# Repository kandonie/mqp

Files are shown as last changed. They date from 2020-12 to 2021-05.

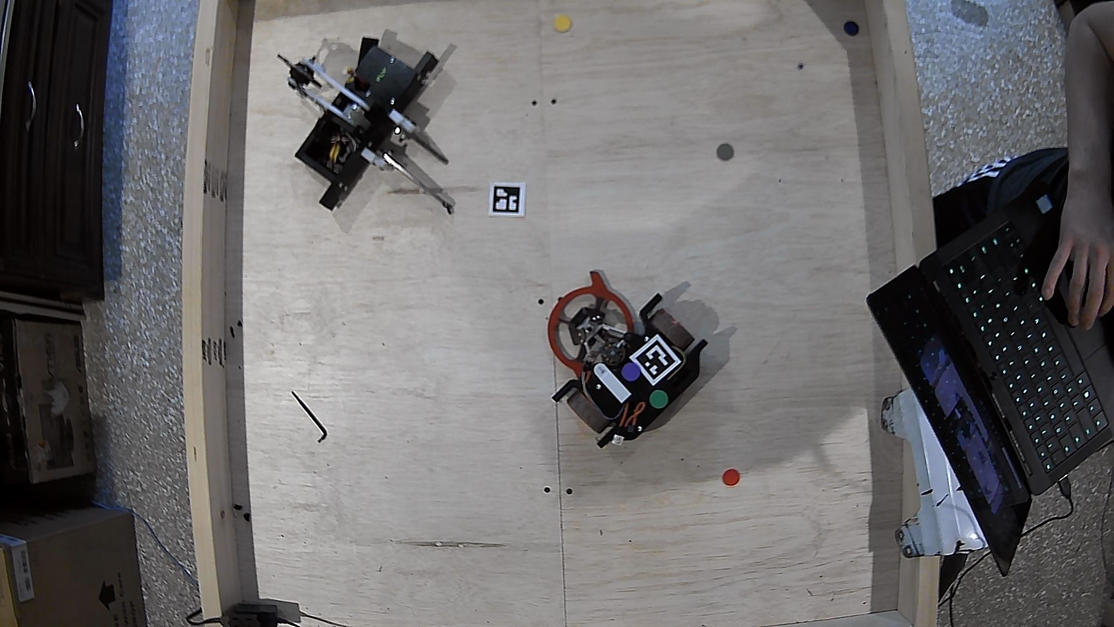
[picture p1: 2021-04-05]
src/CV/tags/OnFiled.png

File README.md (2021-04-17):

To run application:
    python3 main.py <shouldConnectToWiFi> <liveInference>

To run tests:
    python -m pytest tests

shouldConnectToWiFi defaults to True. True tries to connect to WiFi. False will never try to connect
but will also load faster. Good for testing without the ESP
liveInference default to True. true means detecting with webcam, false is using stored images

Currently, things happen based on the GUI. When there is
a change in the GUI, the GUI notifies the state machine (which 
observers the GUI). The state machine's notify currently calls 
appropriate functions on the drive and motor. These call functions
in WiFi to send json info the the ESP. The ESP then makes appropriate
corresponding actions. In the near future, the state machine's notify 
will only update variables. The the runStateMachine will call 
appropriate functions based on those variables.

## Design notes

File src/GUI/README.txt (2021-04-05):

The GUI allows the user to do several things, including viewing data and sending instructions.

The first important feature to note is the ESTOP button in the top left. This will stop the robot.
To the right of this button, we have enable/disable drive and weapon. These buttons determine if
the corresponding motors can more, regaurdless of any state of autonomy.

Next is the intelligence state. Idle means the robot will do nothing. Selecting Remote Control will
open a new window and allow you to drive the robot with the arrow keys. Further instructions reside in
this window. Closing the window brings you back to the main window. Autonomous means the robot will
exercise some autonomous control. For example, you can set the pwm with the GUI and it will move (assuming
drive is enabled), or it may enter a match. The begin match button tells the robot that it is beginning
a combat match and will begin executing the appropriate states of its state maching. Match over sends the
robot into the match over state, where it will perform appropriate actions for a match being over, such as
driving to the door or turning off. Finally, the reset match button reinitializes the robot.

Moving downward, on the left, one can see various data about the robot, provided by the robot. On the right,
the image used by the CV is shown. These are each updated every 500 ms.

At the bottom of the screen lies manual controls for testing the robot. The first column allows you to set
the pwm value of each motor when the button is clicked. The next column allows you to sed the PID values
for all motors when the button is clicked. The next button, set heading, allows you to choose which angle
the robot should turn to face when the button is clicked. Finally, the set distance button tells the robot
to drive a certain distance when clicked.

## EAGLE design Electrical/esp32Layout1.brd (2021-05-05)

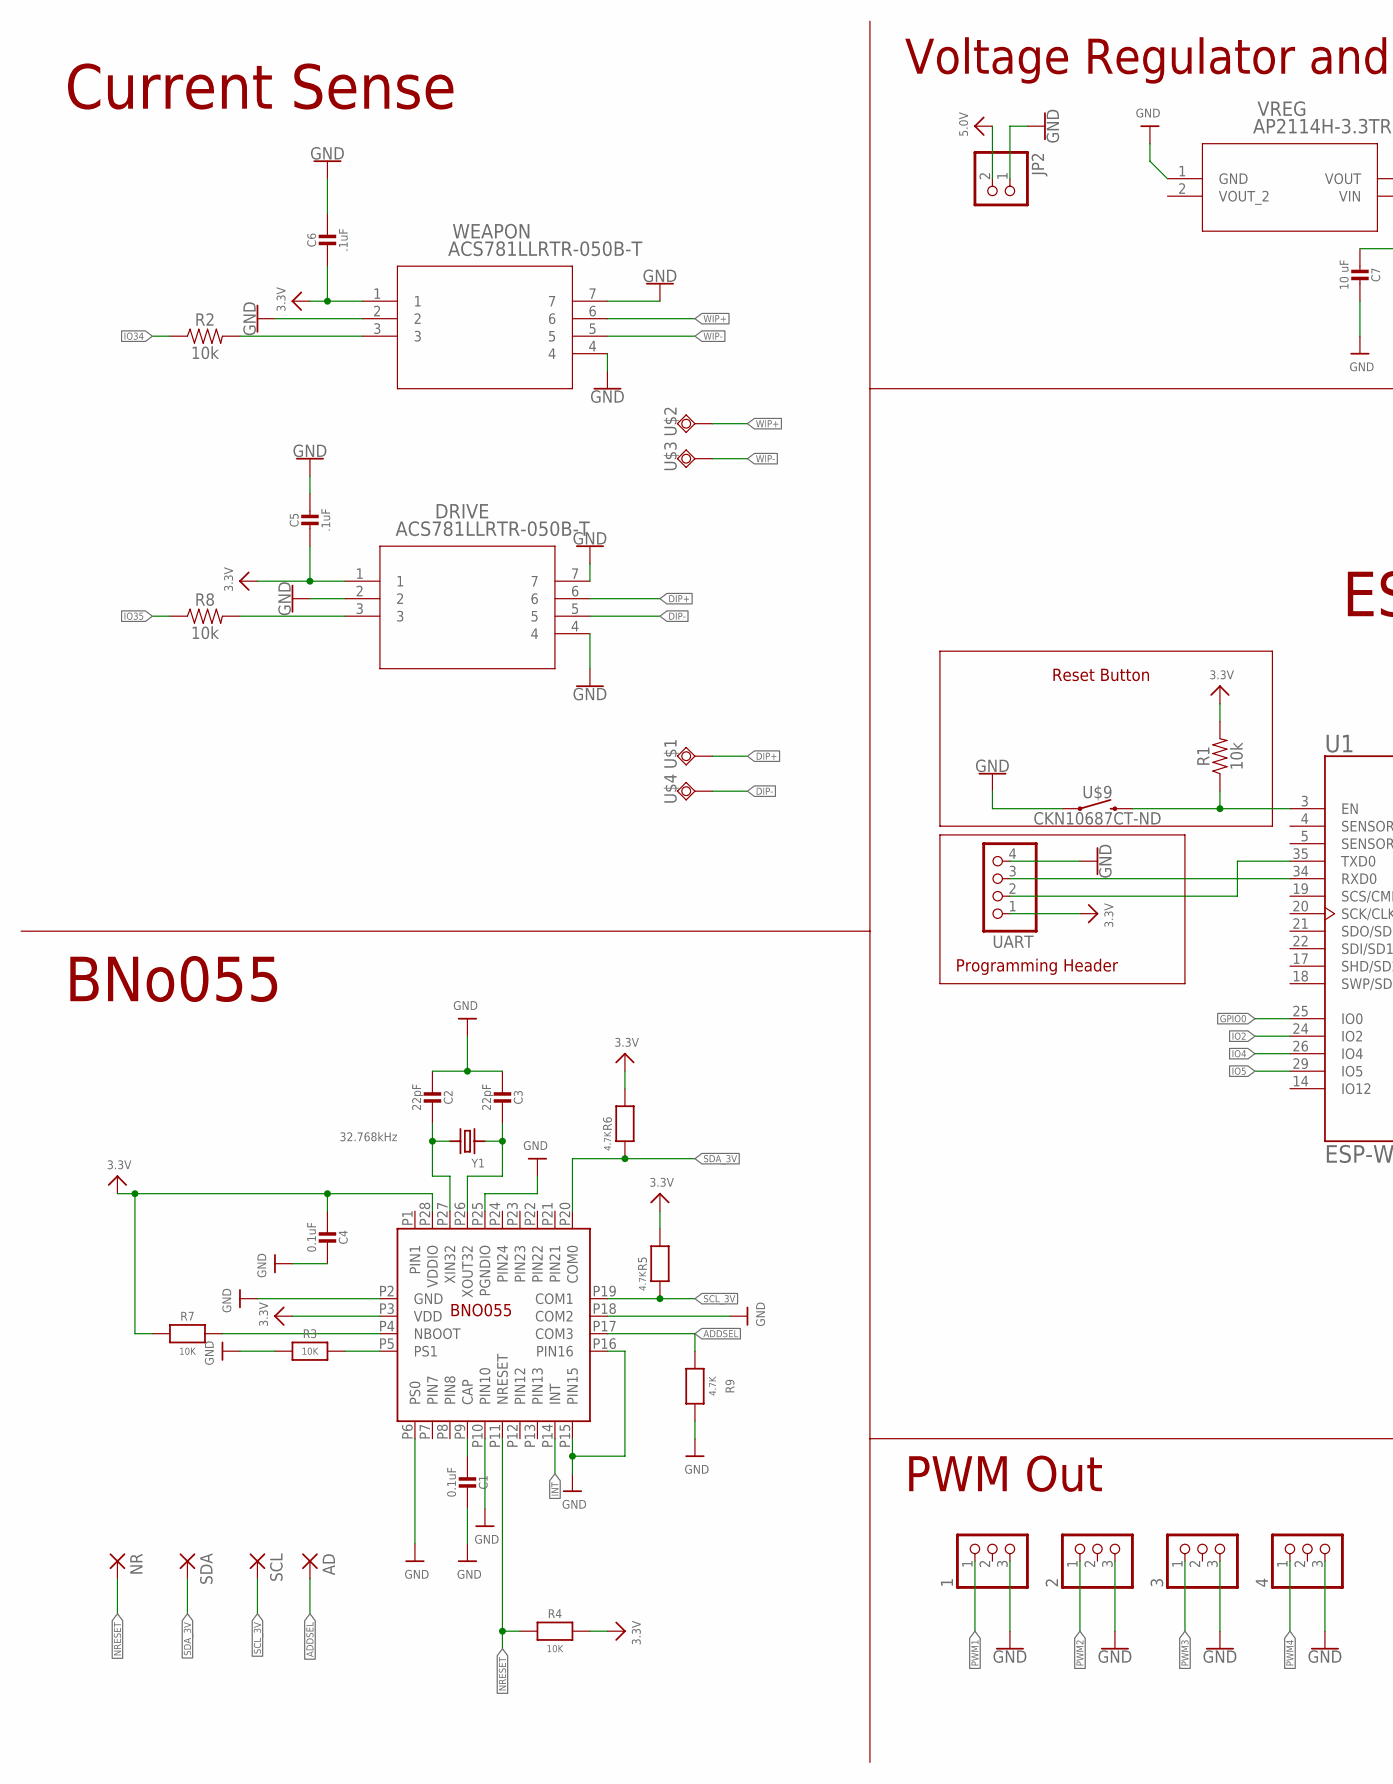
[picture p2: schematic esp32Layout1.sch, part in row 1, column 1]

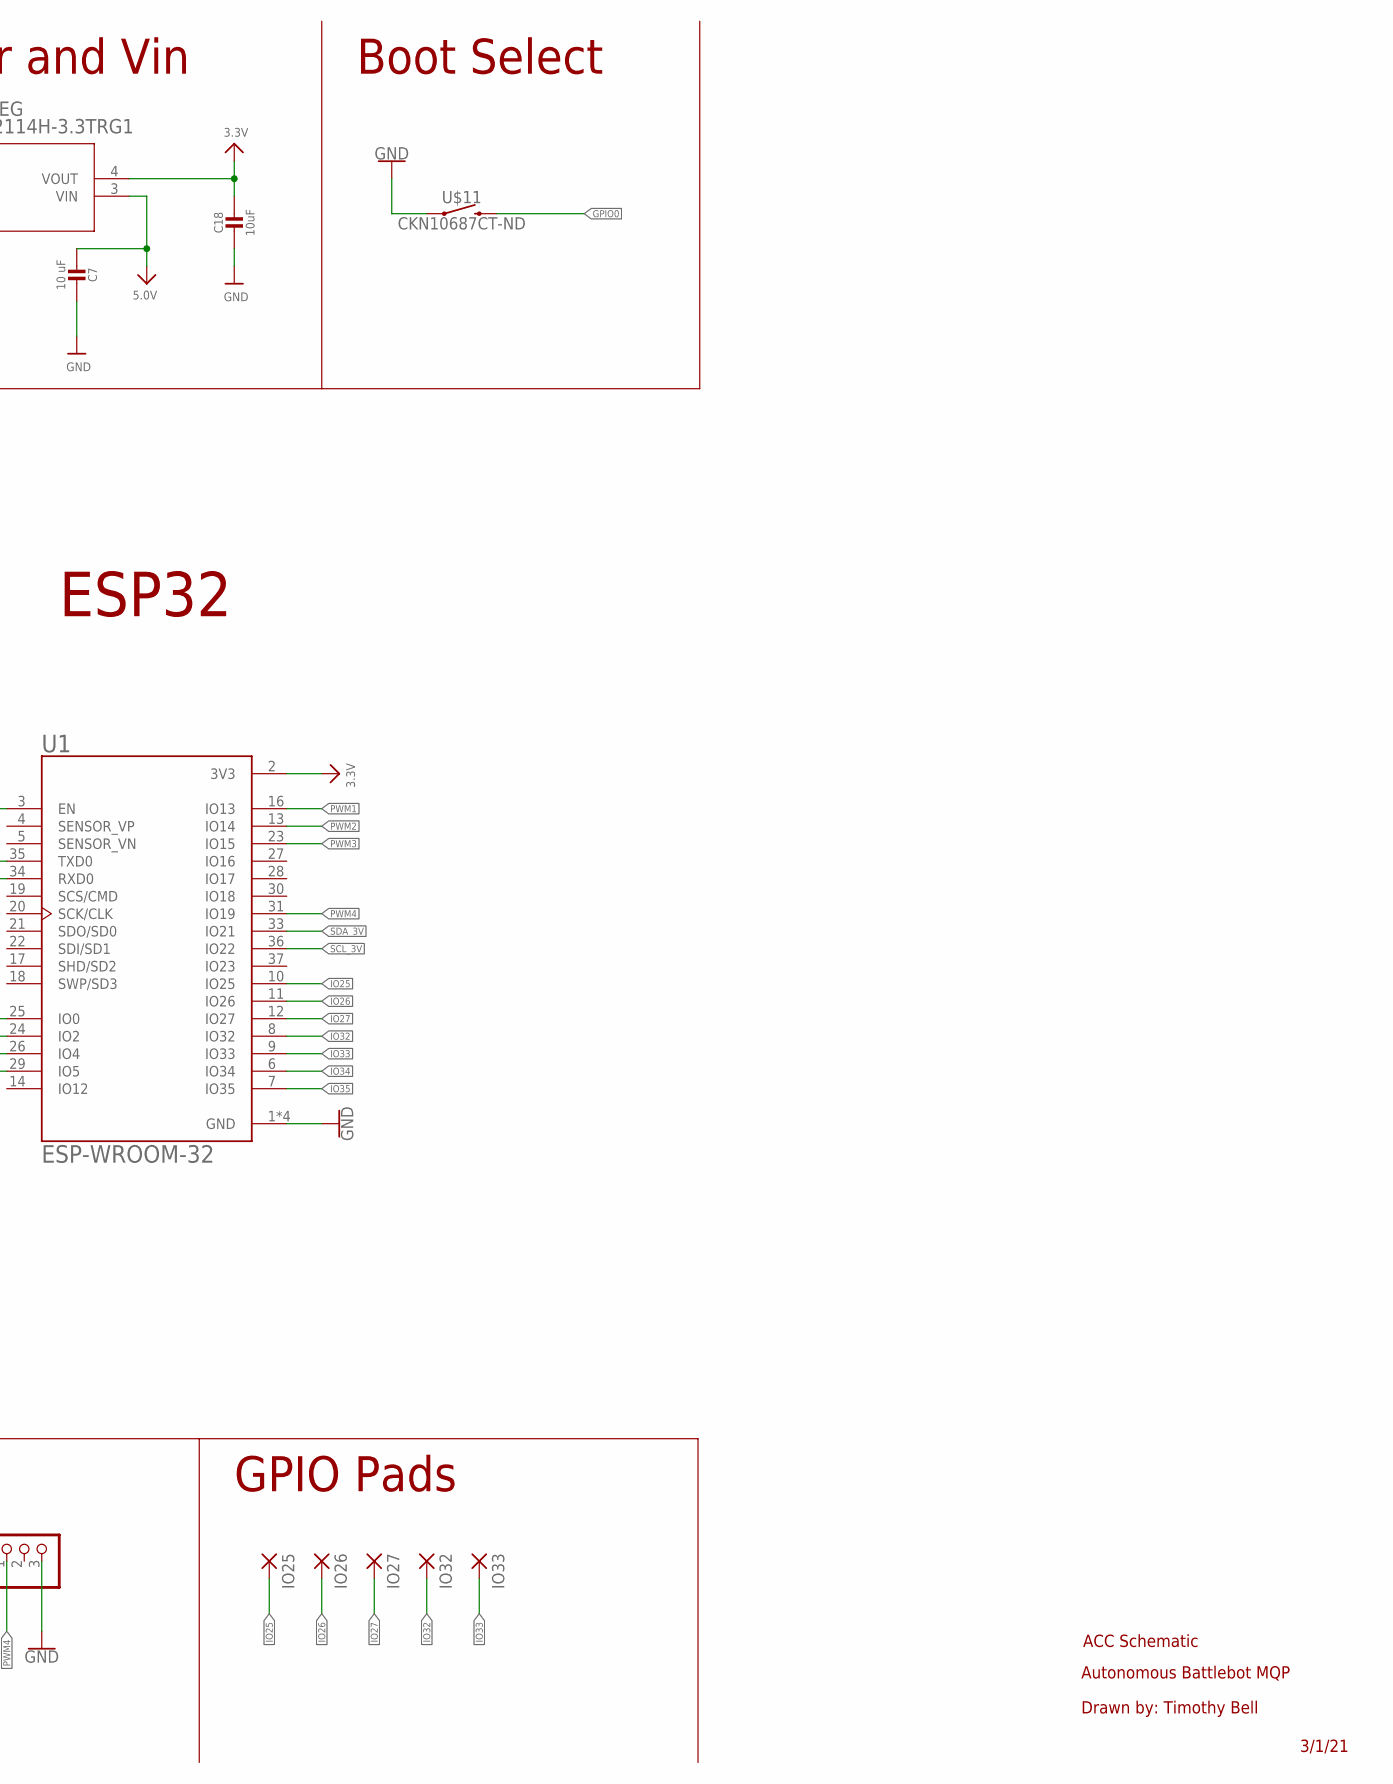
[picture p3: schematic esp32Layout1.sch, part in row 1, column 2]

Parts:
1, 2, 3, 4: PINHD-1X3; 1X03
AD: SMD2; SMD1,27-2,54
BNO055: BNO055
C1, C4: 0.1uF; 0805-NO
C2, C3: 22pF; 0805-NO
C5, C6: .1uF; 0805_10MGAP
C7: 10 uF; 0805-NO
C18: 10uF; 0805_10MGAP
DRIVE: ACS781LLRTR-050B-T; PSOF7_ACS781LLRTR-050B-T_ALM
IO25, IO26, IO27, IO32, IO33: SMD2; SMD1,27-2,54
JP2: PINHD-1X2; 1X02
NR: SMD2; SMD1,27-2,54
R1, R2, R8: 10k; 0603
R3, R4, R7: 10K; 0805-NO
R5, R6, R9: 4.7K; 0805-NO
SCL: SMD2; SMD1,27-2,54
SDA: SMD2; SMD1,27-2,54
U1: ESP-WROOM-32; MODULE_ESP-WROOM-32
U$1, U$2, U$3, U$4: HCURR_PAD
U$9, U$11: CKN10687CT-ND
UART: PINHD-1X4; 1X04
VREG: AP2114H-3.3TRG1; SOT-223_DIO
WEAPON: ACS781LLRTR-050B-T; PSOF7_ACS781LLRTR-050B-T_ALM
Y1: 32.768kHz; CRYSTAL_8X3.8

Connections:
3.3V: BNO055.P3 (VDD), BNO055.P28 (VDDIO), C4.2, C5.2, C6.2, C18.1, DRIVE.1, R1.2, R4.2, R5.2, R6.2, R7.1, U1.2 (3V3), UART.1, VREG.4 (VOUT), WEAPON.1
5.0V: C7.2, JP2.2, VREG.3 (VIN)
ADDSEL: AD.1, BNO055.P17 (COM3), R9.1
DIP+: DRIVE.6, U$1.P$1
DIP-: DRIVE.5, U$4.P$1
GND: 1.3, 2.3, 3.3, 4.3, BNO055.P2 (GND), BNO055.P6 (PS0), BNO055.P10 (PIN10), BNO055.P15 (PIN15), BNO055.P16 (PIN16), BNO055.P18 (COM2), BNO055.P25 (PGNDIO), C1.1, C2.2, C3.2, C4.1, C5.1, C6.1, C7.1, C18.2, DRIVE.2, DRIVE.4, DRIVE.7, JP2.1, R3.1, R9.2, U1.1 (GND), U1.1.1 (GND), U1.15 (GND), U1.38 (GND), U$9.P$1 (1), U$9.P$2 (1), U$11.P$1 (1), U$11.P$2 (1), UART.4, VREG.1 (GND), WEAPON.2, WEAPON.4, WEAPON.7
GPIO0: U1.25 (IO0), U$11.P$3 (2), U$11.P$4 (2)
INT: BNO055.P14 (INT)
IO2: U1.24 (IO2)
IO4: U1.26 (IO4)
IO5: U1.29 (IO5)
IO25: IO25.1, U1.10 (IO25)
IO26: IO26.1, U1.11 (IO26)
IO27: IO27.1, U1.12 (IO27)
IO32: IO32.1, U1.8 (IO32)
IO33: IO33.1, U1.9 (IO33)
IO34: R2.1, U1.6 (IO34)
IO35: R8.1, U1.7 (IO35)
unnamed: BNO055.P5 (PS1), R3.2
unnamed: R1.1, U1.3 (EN), U$9.P$3 (2), U$9.P$4 (2)
unnamed: U1.35 (TXD0), UART.2
unnamed: U1.34 (RXD0), UART.3
unnamed: R2.2, WEAPON.3
unnamed: BNO055.P9 (CAP), C1.2
unnamed: BNO055.P27 (XIN32), C2.1, Y1.P$4 (2)
unnamed: BNO055.P26 (XOUT32), C3.1, Y1.P$1 (1)
unnamed: BNO055.P4 (NBOOT), R7.2
unnamed: DRIVE.3, R8.2
NRESET: BNO055.P11 (NRESET), NR.1, R4.1
PWM1: 1.1, U1.16 (IO13)
PWM2: 2.1, U1.13 (IO14)
PWM3: 3.1, U1.23 (IO15)
PWM4: 4.1, U1.31 (IO19)
SCL_3V: BNO055.P19 (COM1), R5.1, SCL.1, U1.36 (IO22)
SDA_3V: BNO055.P20 (COM0), R6.1, SDA.1, U1.33 (IO21)
WIP+: U$2.P$1, WEAPON.6
WIP-: U$3.P$1, WEAPON.5

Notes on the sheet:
BNo055
ESP32
Current Sense
PWM Out
Voltage Regulator and Vin
GPIO Pads
Boot Select
ACC Schematic
Autonomous Battlebot MQP
Drawn by: Timothy Bell
3/1/21
Reset Button
Programming Header

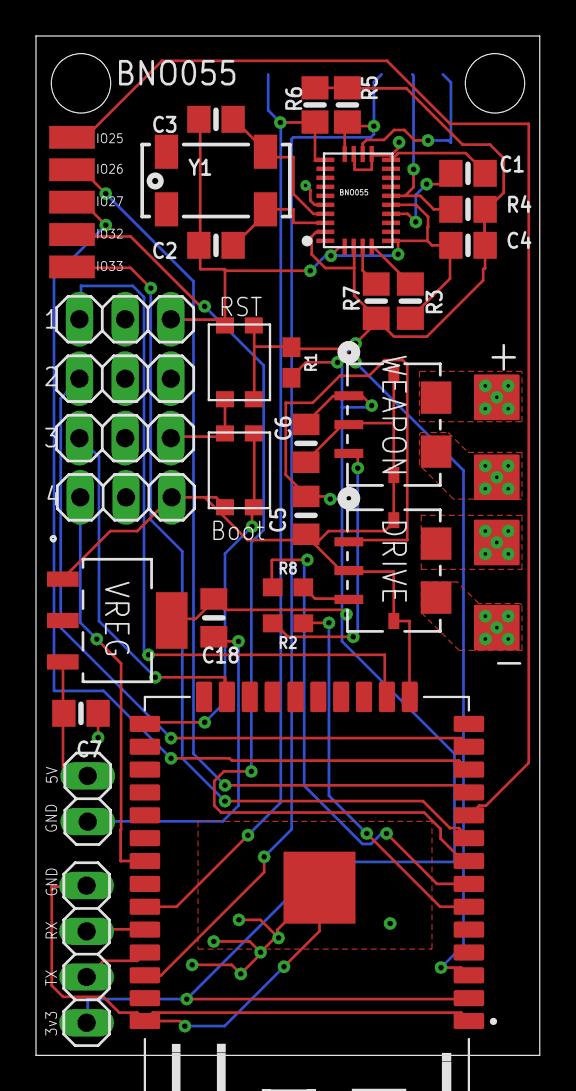
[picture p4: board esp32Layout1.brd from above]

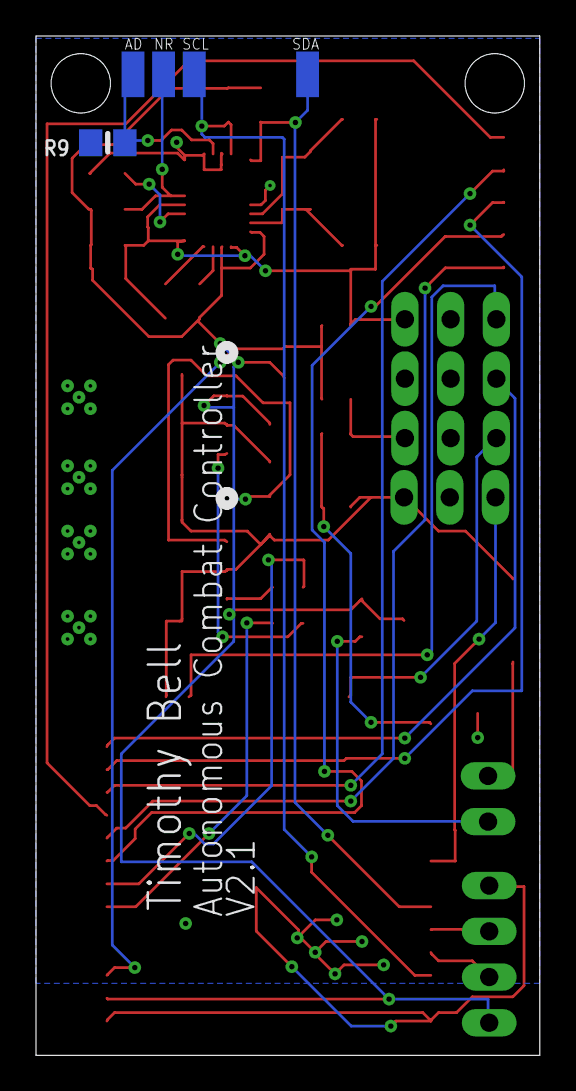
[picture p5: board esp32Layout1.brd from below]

Board: 2 copper layers, 28.0 x 56.6 mm, 44 parts (5 on the bottom side), 33 nets.

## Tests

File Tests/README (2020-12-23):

To run tests, from the mqp directory:
    python -m pytest tests

For test coverage:
in Windows
    python -m pytest --cov=<PathToMQP>\mqp tests --cov-report html --cov-report term-missing
ex)
 I apologize for my Windows path
 python -m pytest --cov=C:\Users\lhatf\Documents\GitHub\mqp tests --cov-report html --cov-report term-missing

for Linux just use Linux path with / instead of \

this will create a htmlcov directory which shows coverage results. Look at index.htm first then other .html
files for specific lines hit/missed on each file

you will want to do a pip install pytest-cov
if you want to make new tests, you NEED to have an __init__.py in every directory
used for an import or it will complain along the lines of "Can't import Module 'xxx'"

for example, from src.GUI.mainWindow import MainWindow
needs a __init__.py file in the src/ and src/GUI directories

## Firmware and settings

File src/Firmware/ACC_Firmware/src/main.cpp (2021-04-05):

#include <Arduino.h>
#include <ArduinoJson.h>
#include "WiFi.h"
#include "ESPAsyncWebServer.h"
#include "iostream"
#include "string.h"
#include <Wire.h>
#include <Adafruit_Sensor.h>
#include <Adafruit_BNO055.h>
#include "movement.h"
#include "sensors.h"

using namespace std;

const char *ssid = "#wewantseason";
const char *password = "ap1@Lancast";
// Create AsyncWebServer object on port 80
AsyncWebServer server(80);

char general[] = "/general";
char ESTOP[] = "/ESTOP";
char APOS[] = "/readAPOS";
char robotDataJson[] = "/getRobotData";

//mutex - varible names
int motor1PWM = 1500;
int motor2PWM = 1500;
int weaponPWM = 0;
boolean weaponArmed = false;
boolean driveArmed = false;


String robotMovementType;

//Robot State variable triggers
boolean robotDisabled = true;

double desiredHeading = 180;
double currHeading = 0;

double weaponCurrent;
double driveCurrent;
int startTime = 0;

// Encoder setup
volatile int encoder1Ticks = 0;
volatile int encoder2Ticks = 0;
double desiredDist = 0;
const byte encoder1Pin = 25;
const byte encoder2Pin = 26;
portMUX_TYPE mux = portMUX_INITIALIZER_UNLOCKED;

//Interrupt Booleans
boolean checkGyro;
boolean checkCurrent;

//JSON Library declarations
StaticJsonDocument<300> doc;
StaticJsonDocument<200> robotDataDoc;


unsigned long SensorPrevTime = 0; //prevtime is the previous time that the bno055 was polled
unsigned long mainTime;

//Robot States
static enum stateChoices {
  disabled,
  teleop,
  autonomous,
  configureRobot,
  updateSensors
} state,
    previousState;

String readAPOS() {
  //This should check a global variable with the last heading reading
  Serial.println("Read APOS");
  return "North";
}

String emergencyStop() {
  estopRobot();
  return "Robot has ESTOPPED";
}

String getRobotData() {
  robotDataDoc["getHeading"] = (int) currHeading;
  robotDataDoc["getDriveCurrent"] = 0.25;
  robotDataDoc["getWeaponCurrent"] = 0.5;

  char buffer[200];
  serializeJson(robotDataDoc, buffer);
  return buffer;
}

String generalHandler()
{

  return "0";
}


// Encoder ISRs
void IRAM_ATTR encoder1ISR() {
  // Check motor direction then increment/decrement accordingly
  portENTER_CRITICAL_ISR(&mux);
  if(motor1PWM>1500){
    encoder1Ticks++;
  } else{
    encoder1Ticks--;
  }
  portEXIT_CRITICAL_ISR(&mux);
}

void IRAM_ATTR encoder2ISR() {
  // Check motor direction then increment/decrement accordingly
  portENTER_CRITICAL_ISR(&mux);
  if(motor2PWM>1500){
    encoder2Ticks++;
  } else{
    encoder2Ticks--;
  }
  portEXIT_CRITICAL_ISR(&mux);

}

void encoderSetup(){
      //encoder pin interrupt configuration
    pinMode(encoder1Pin, INPUT);
    pinMode(encoder2Pin, INPUT);
    attachInterrupt(digitalPinToInterrupt(encoder1Pin), encoder1ISR, RISING);
    attachInterrupt(digitalPinToInterrupt(encoder2Pin), encoder2ISR, RISING);
}

//testing 

void setup()
{
  // put your setup code here, to run once:
  Serial.begin(115200);
  delay(2000);
  Serial.println("I am Alive");

  // Setting the ESP as an access point
  Serial.print("Setting AP (Access Point)…");
  // Remove the password parameter, if you want the AP (Access Point) to be open

  //Uncomment to host esp access point

  
  // WiFi.softAP(ssid, password);
  // IPAddress IP = WiFi.softAPIP();
  // Serial.print("AP IP address: ");
  // Serial.println(IP);
  
  // Uncomment to connect to wifi

  WiFi.begin(ssid, password);
  while (WiFi.status() != WL_CONNECTED)
  {
    delay(1000);
    Serial.println("Connecting to WiFi..");
  }
  Serial.println(WiFi.localIP());

  //Get Requests (Test Request)
  //todo change APOS get request to robot data json
  //todo serilize to a json
  server.on(APOS, HTTP_GET, [](AsyncWebServerRequest *request) { //Angular Position Get From Robot
    request->send_P(200, "text/plain", readAPOS().c_str());
  });

  //ESTOP Request
  server.on(ESTOP, HTTP_GET, [](AsyncWebServerRequest *request) { //Angular Position Get From Robot
    request->send_P(200, "text/plain", emergencyStop().c_str());
  });

  // gyro data Request
  server.on(robotDataJson, HTTP_GET, [](AsyncWebServerRequest *request) { //Angular Position Get From Robot
    request->send_P(200, "text/plain", getRobotData().c_str());
  });

  server.on(
      "/generaltest",
      HTTP_POST,
      [](AsyncWebServerRequest *request) {},
      NULL,
      [](AsyncWebServerRequest *request, uint8_t *data, size_t len, size_t index, size_t total) {
        char json[] = "ccccccccccccccccccccccccccccccccccccccccccccccccccccccccccccccccccccccccccccccccccccccccccccccccccccccccccccccccccccccccccccccccccccccccccccccccccccbbbbbbbbbbbbbbbbbbbbbbbbbbbbbbbbbbbbbbbbbbbbbbbbbbbbbbbbbbbbbbbbbbbbbbbbbbbbbbbbbbbbbbbbbbbbbbbbbbbbbbbbbbbbbbbbbbbbbbbbbbbbbbbbbbbbbbbbbbbbbbbbbbbbbbbbbbbbbbbbbbbbbbbbbbbbbbbbbbbbbbbbbbbbbbbaaaaaaaaaaaaaaaaaaaaaaaaaaaaaaaaaaaaaaaaaaaaaaaaaaaaaaaaaaaaaaaaaaaaaaaaaaaaaaaaaaaaaaaaaaaaaaaaaaaaaaaaaaaaaaaaaaaaaaaaaaaaaaaaaaaaaaaaaaaaaaaaaaaaaaaaaaaaaaaaaaaaaaaaaaaaaaaaaaaaaaaaaaaaaaaaaaaaaaaaaaaaaaaaaaaaaaaaaaaaaaaaaaaaaaaaaaaaaaaaaaaaaaaaaaaaaa";
        // TODO actual memory safety
        int jsonIndex = 0;
        for (size_t i = 0; i < len; i++)
        {

          //Serial.write(data[i]);
          if (data[i] == ' ')
          {
            continue;
          }
          else
          {
            json[jsonIndex] = data[i];
            jsonIndex++;
          }
        }
        Serial.println("");
        char newJson[jsonIndex + 1];
        strncpy(newJson, json, jsonIndex);
        newJson[jsonIndex] = '\0';
        // Serial.println(newJson); //print the whole json

        DeserializationError error = deserializeJson(doc, newJson);

        // Test if parsing succeeds.

        //TODO Return 404 error
        if (error)
        {
          Serial.print(F("deserializeJson() failed: "));
          Serial.println(error.f_str());
          return;
        }

        //TODO MAKE THE ROBOT NOT CRASH HERE IF IT DOESN'T FIND THE KEY
        // deserializeJSON comes from the ESPHTTPTopics.py
        motor1PWM = doc["motor1pwm"];
        motor2PWM = doc["motor2pwm"];
        weaponPWM = doc["weapon_pwm"];
        robotMovementType = doc["RobotMovementType"].as<const char *>();
        auto weaponTest = doc["WeaponArmedState"].as<const char *>(); //adding this greatly increased RTT, but should be double checked
        auto driveTest = doc["ArmDriveState"].as<const char *>();
        bool tuning_kp = doc["tuning_kp"];
        bool tuning_ki = doc["tuning_ki"];
        bool tuning_kd = doc["tuning_kd"];
        bool setting_heading = doc["setting_heading"];
        bool setting_distance = doc["setting_distance"];

        static double kp = .2;
        static double ki = 0;
        static double kd = 0;

        if (tuning_kp) {
          kp = doc["kp"];
        }
        else if (tuning_ki) {
          ki = doc["ki"];
        }
        else if (tuning_kd) {
          kd = doc["kd"];
        }

        if (setting_heading){
          desiredHeading = doc["desiredHeading"];
          desiredHeading = 360 - desiredHeading;
    
        }

        if (setting_distance){
          desiredDist = doc["desiredDistance"];
        }

        driveArmed = doc["ArmDriveState"];
        //Serial.print("JSON TEST Print  ");
        //Serial.println(motor1PWM);

        // set pid gains based on json input
        setPIDGains(kp, ki, kd);

        // ARM and Disarm checks
        if (strcmp(weaponTest, "false") == 0)
        {
          weaponArmed = false;
        }
        else
        {
          weaponArmed = true;
        }

        if (strcmp(driveTest, "false") == 0)
        {
          driveArmed = false;
        }
        else
        {
          driveArmed = true;
        }

        if (robotMovementType.equals("gyroMode"))
        {
          state = autonomous;
        }

        request->send(200);
        Serial.println("Response Sent");
        mainTime = millis();
      });

  //start the webserver
  server.begin();

  //motion setup
  //if not connected to wifi nothing should move
  movementSetup();
  sensorSetup();

  state = teleop;

  Serial.println("End Of Calibration");
  delay(1000);

  mainTime = millis();
}

void updateTime()
{
  //this should probably watch for overflow on mainTime
  mainTime = millis();
}

void loop()
{

  switch ((state))
  {
  case disabled:
    Serial.println("State Disabled");
    /* code */
    disablePWM("all");
    if (robotDisabled)
    {
      state = disabled;
    }
    else
    {
      state = configureRobot;
    }
    break;

  case updateSensors:

    updateTime();

    //the minimum value for this is 10 milliseconds, the BNo055 will not provide data faster over i2c
    if (mainTime - SensorPrevTime > 15)
    {
      measureCurrent();
      weaponCurrent = currentCheck("sensor1");
      driveCurrent = currentCheck("sensor2");
      updateGyroData();
      currHeading = getGyroData();
      //isUpsideDown();
      //Serial.println(getGyroData());
      SensorPrevTime = mainTime;
      //Serial.println("Reading GYRO");
    }

    state = previousState;
    previousState = updateSensors;

    break;

  case teleop:

    //movement functions need to be aware of arm and disarm states
    //Serial.println("Teleop");
    updateTime();
    //Serial.println("In Teleop");
    if (weaponArmed)
    {
      if (PWMWeaponDisabled())
      {
        enablePWM("weapon");
      }
      //Serial.println(currentCheck("sensor1"));
      setWeapon(weaponPWM);
    }
    else
    {
      disablePWM("weapon");
    }

    if (driveArmed)
    {
      if (PWMDriveDisabled())
      {
        enablePWM("drive");
      }
      setRight(motor1PWM);
      setLeft(motor2PWM);
    }
    else
    {
      disablePWM("drive");
    }

    previousState = state;
    state = updateSensors;
    //state = teleop;

    /* code */
    // leave teleop if the state is changed by the control system
    // change variable with json

    break;

  case autonomous:
    updateTime();

    //turn to a defined angle
    if (robotMovementType.equals("gyroMode"))
    {
      if (turnToAngle(currHeading, desiredHeading))
      { //turnToAngle returns true when the robot is at the correct heading
        disablePWM("drive");
        robotMovementType = "gyroMode";
      }
      else
      {
        robotMovementType = "gyroMode";
      }
    }

    if(robotMovementType.equals("waiting")){
      disablePWM("drive");
    }

       //drive a set distance
    // Need actual JSON word
    if (robotMovementType.equals("driveDistance")){
      if (driveDistance(encoder1Ticks, desiredDist)){
        robotMovementType = "waiting";
      }
      else
      {
        robotMovementType = "driveDistance";
      }
    }


    //drive a set distance

    //Serial.println("State Autonomous");

    previousState = state;
    state = updateSensors;

    break;

  case configureRobot:
    disablePWM("all");
    Serial.println("State configure robot");

    break;

  default:
    break;
  }

}

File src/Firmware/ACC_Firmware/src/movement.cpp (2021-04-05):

#include "ESP32Servo.h"
#include "Arduino.h"

#define FULL_CW 2000
#define FULL_CCW 1000
#define STOPPED 1500

Servo Motor1;
Servo Motor2;
Servo Motor3;
Servo Motor4;

//motor 1 is right side
//motor 2 is left side
//2000 is full reverse 
//1000 if full forwards

//from robot prespective motor 2 is left
//and motor 1 is right

const int motorPin = 13;
const int motor2Pin = 14;
const int motor3Pin = 15;
const int motor4Pin = 19; 

boolean PWMDisabledDrive = false;
boolean PWMDisabledWeapon = false;

//PID variables
double error;
double totalError;
double previousError = 0;

//PID Variables for driveDistance
double error1;
double totalError1;
double previousError1 = 0;
double error2;
double totalError2;
double previousError2 = 0;

double kp = 0;
double ki = 0;
double kd = 0;


void brushlessNeutral(){
    Motor1.writeMicroseconds(STOPPED);
    Motor2.writeMicroseconds(STOPPED);
}

void setPIDGains(double proportional, double integral, double derivative) {
    kp = proportional;
    ki = integral;
    kd = derivative;
}


int checkPWM(int pwm){
    if (pwm > 1600) {
    pwm = 1600;
    }
    if (pwm < 1400) {
        pwm = 1400;
    }
    return pwm;
}

void disablePWM(String system){

    if(system.equals("drive")){
        brushlessNeutral();
        PWMDisabledDrive = true;
    } 
    else if(system.equals("weapon")){
        PWMDisabledWeapon = true;
    } 
    else if(system.equals("all")){
        brushlessNeutral();
        PWMDisabledDrive = true;
        PWMDisabledWeapon = true;
    } 


}


//ESTOP is a non recoverable function,the robot must be power cycled after an ESTOP 
void estopRobot(){

    brushlessNeutral();
    delay(100);
    //disable pwm on motor ports
    Motor1.detach();
    Motor2.detach();
    Motor3.detach();
    Motor4.detach();

    Serial.println("Robot is ESTOPPED, Power Off Robot");
    delay(500);

}


//old code, just used for keeping track of robot enabled states
void enablePWM(String system){

    if(system.equals("drive")){ 
        PWMDisabledDrive = false;
    } 
    else if(system.equals("weapon")){
        PWMDisabledWeapon = false;
    } 
    else if(system.equals("all")){
        PWMDisabledDrive = false;
        PWMDisabledWeapon = false;
    } 
}

void movementSetup()
{
    //enablePWM("all");
    Motor1.attach(motorPin, 1000, 2000);   // left motor
    Motor2.attach(motor2Pin, 1000, 2000);  // right motor
    Motor3.attach(motor3Pin, 1000, 2000);   // left motor
    Motor4.attach(motor4Pin, 1000, 2000);

    Motor1.setPeriodHertz(60);
    Motor2.setPeriodHertz(57);
    Motor3.setPeriodHertz(56);
    Motor4.setPeriodHertz(55);
    Motor1.writeMicroseconds(1500);
    Motor2.writeMicroseconds(1500);
    delay(2000);
}

void setRight(int speed)
{   
    speed = checkPWM(speed);
    Motor1.writeMicroseconds(speed);
}

void setLeft(int speed)
{
    speed = checkPWM(speed);
    Motor2.writeMicroseconds(speed);
}

// set the motor speeds so the robot turns
// @param speed a range from 1000-2000
// @param direction a string that is either "CW" or "CCW"
void turnSpeed(int speed, String direction){
    if (direction == "CCW") {
        setLeft(speed);
        setRight(FULL_CW - abs(speed - FULL_CCW));
    } else {
        setLeft(FULL_CW - abs(speed - FULL_CCW));
        setRight(speed);
    }
}

void setWeapon(int speed){
    speed = checkPWM(speed);
    Motor3.writeMicroseconds(speed);
}

boolean PWMDriveDisabled(){
    return PWMDisabledDrive;
}

boolean PWMWeaponDisabled() {
    return PWMDisabledWeapon;
}



bool turnToAngle(double currentHeading, double desiredHeading) {
    //Serial.println("Turning to angle");
    if (desiredHeading > 360){
        disablePWM("drive");
        Serial.println("Desired Heading Out Of Range");
        return true;
    }
    error = ((int)currentHeading - (int)desiredHeading)%360;
    // Serial.print("Current Heading  ");
    // Serial.print(currentHeading);
    // Serial.print("Desired Heading ");
    // Serial.println(desiredHeading);

    if (error > 180){
        error = 360 - error;
    } else if (error < -180){
        error = 360 + error;
    }
    //Serial.print("Error  : ");
    //Serial.print(error);
    //Serial.print("   Heading  : ");
    //Serial.println(currentHeading);
    String direction;

    if(abs(currentHeading - desiredHeading) > 180){
        direction = "CW";
    } else {
        direction = "CCW";
    }

    totalError += error;
    double proportional = error*kp;
    double integral = totalError*ki;
    double derivative = (error - previousError)*kd;

    int output = proportional + integral + derivative;

    // an output of range 0-1000 will be mapped to pwm range 1500-2000
    int speed = map(output, 0, 50, STOPPED, FULL_CW);
    // constrain to pwm range 1000-2000 so negative output values can make motors go backwards
    speed = constrain(speed, FULL_CCW, FULL_CW);

    //check turn angle
    turnSpeed(speed, direction);

    //reset setpoints when target is hit
    previousError = error;

    //arbitrary error for now
    if(abs(error) < 10){
        disablePWM("drive");
        Serial.println("Reached Angle");
        return true;
    }

    return false;

}


bool driveDistance(int encoderTicks, double distGoal){
    if(distGoal > 50){
        Serial.println("Distance goal too large");
        return true;
    }
    // Convert encoder ticks to wheel revolutions
    // 14 motor poles, 52:855 gearbox reduction
    double wheelPos = encoderTicks*14*52/855;
    //Convert goals to wheel revolutions
    double wheelGoal = distGoal/(2.75*3.14);

    // Set error for PID
    error1 = wheelGoal - wheelPos;

    totalError1 += error1;
    double proportional = error1*kp;
    double integral = totalError1*ki;
    double derivative = (error1 - previousError1)*kd;

    int output = proportional + integral + derivative;

    // Map output over full PWM range
    int speed = map(output, -50, 50, FULL_CCW, FULL_CW);
    
    // Set drive speeds
    setRight(speed);
    setLeft(speed);

    previousError1 = error1;
    
    //arbitrary error for now in rotations of wheel
    if(error < .125){
        return true;
    }

    return false;
}

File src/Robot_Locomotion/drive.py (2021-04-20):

from src.Hardware_Comms.ESPHTTPTopics import SetJSONVars, RobotMovementType
from src.Robot_Locomotion.MotorEnums import PWMVals
from src.CV.CVTopics import CVTopics
from src.Hardware_Comms import ESPHTTPTopics, WiFiComms
import threading, time


class Drive:
    """
    the computer representation of the drive
    """

    def __init__(self, wifi):
        """
        initializes drive
        :param wifi:  the wifi
        """
        self.wifi = wifi
        self.CVData = {}
        for item in CVTopics:
            self.CVData[item] = 0
        self.driveLock = threading.Lock()

    def stop(self):
        """
        sets the speeds of both motors to 0
        """
        self.wifi.sendInfo({SetJSONVars.MOTOR1_PWM.value: PWMVals.STOPPED.value,
                            SetJSONVars.MOTOR2_PWM.value: PWMVals.STOPPED.value,
                            SetJSONVars.MOVEMENT_TYPE.value: RobotMovementType.PWM_CONTROLLED.value})

    def driveSpeed(self, speed):
        """
        drives stright at speed
        :param speed: [String] the speed to drive at
        """
        print("driving with PWM: " + str(speed))
        if int(speed) > int(PWMVals.FULL_CW.value):
            speed = PWMVals.FULL_CW.value
        elif int(speed) < int(PWMVals.FULL_CCW.value):
            speed = PWMVals.FULL_CCW.value
        self.setPWM(SetJSONVars.MOTOR1_PWM.value, speed)
        self.setPWM(SetJSONVars.MOTOR2_PWM.value, speed)
        self.wifi.sendInfo(
            {SetJSONVars.MOVEMENT_TYPE.value: RobotMovementType.PWM_CONTROLLED.value})

    def disable(self):
        self.stop()

    def turnAngle(self, angle):
        """
        turns the robot to angle
        :param angle: [String] The relative angle to turn to in degrees
        """
        print("Turning " + str(angle) + " degrees")
        self.wifi.sendInfo({SetJSONVars.DESIRED_HEADING.value: str(angle),
                            SetJSONVars.MOVEMENT_TYPE.value: RobotMovementType.TURN_ANGLE.value})

    def turnSpeed(self, speed):
        """
        turns the robot at a speed
        :param speed: [String] The speed in pwm at which to rotate
        """

        # check bounds
        if int(speed) > int(PWMVals.FULL_CW.value):
            speed = PWMVals.FULL_CW.value
        elif int(speed) < int(PWMVals.FULL_CCW.value):
            speed = PWMVals.FULL_CCW.value

        # direction
        if int(speed) > int(PWMVals.STOPPED.value):
            invertedSpeed = int(speed) - int(PWMVals.STOPPED.value)
            invertedSpeed = str(int(PWMVals.STOPPED.value) - invertedSpeed)
            self.setPWM(SetJSONVars.MOTOR1_PWM.value, speed)
            self.setPWM(SetJSONVars.MOTOR2_PWM.value, invertedSpeed)
        else:
            invertedSpeed = int(PWMVals.STOPPED.value) - int(speed)
            invertedSpeed = str(invertedSpeed + int(PWMVals.STOPPED.value))
            self.setPWM(SetJSONVars.MOTOR1_PWM.value, speed)
            self.setPWM(SetJSONVars.MOTOR2_PWM.value, invertedSpeed)
        # start this movement type
        self.wifi.sendInfo(
            {SetJSONVars.MOVEMENT_TYPE.value: RobotMovementType.PWM_CONTROLLED.value})

    def driveDistance(self, distance):
        """
        drives a distance
        :param distance: [int] the distance in meters
        """
        print("Driving " + str(distance) + " meters")
        self.wifi.sendInfo({SetJSONVars.DESIRED_DISTANCE.value: str(distance),
                            SetJSONVars.MOVEMENT_TYPE.value: RobotMovementType.DRIVE_DISTANCE.value})

    def setPWM(self, motor, pwm):
        """
        sets the pwm of drive motors
        :param motor: the motor
        :param pwm:  the pwm
        """
        self.wifi.sendInfo({motor: pwm})

    def driveToOpponent(self):
        """
        drives toward the opponent based on CV target heading and target distance
        """
        targetHeading = self.CVData[CVTopics.TARGET_HEADING]
        targetDistance = self.CVData[CVTopics.TARGET_DISTANCE]
        heading = self.CVData[CVTopics.HEADING]
        if abs(targetHeading - heading) > 15:
            if targetHeading < 0:
                targetHeading += 360
            self.wifi.sendInfo({SetJSONVars.SETTING_HEADING.value: 1,
                                SetJSONVars.DESIRED_HEADING.value: targetHeading,
                                SetJSONVars.MOVEMENT_TYPE.value: RobotMovementType.TURN_ANGLE.value})
            self.wifi.sendInfo({SetJSONVars.SETTING_HEADING.value: 0})
        else:
            self.wifi.sendInfo({SetJSONVars.SETTING_DISTANCE.value: 1,
                                SetJSONVars.DESIRED_DISTANCE.value: str(targetDistance),
                                SetJSONVars.MOVEMENT_TYPE.value: RobotMovementType.DRIVE_DISTANCE.value})
            self.wifi.sendInfo({SetJSONVars.SETTING_DISTANCE.value: 0})

    def notify(self, topic, value):
        # if we've had a change or is first time
        self.driveLock.acquire(True)
        if value != self.CVData[topic]:
            self.CVData[topic] = value
            self.driveLock.release()
        else:
            self.driveLock.release()

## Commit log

2020-10-26 Added basic GUI for ESTOP, Intelligence State, and PWM
2020-10-27 made function prototypes
2020-11-02 sensor functions
2020-11-06 testing movement with hardcoded pwm
2020-11-06 tried to fix with calibration but robot not spinning motors after wifi command
    [main.cpp, movement.cpp]
2020-11-17 state machine actually works by calling states, added polygon and PWM states. Also added a Lock for robotData cuz threads sharing data
2020-11-25 Working json parsing on robot, can set robot pwm
2020-11-25 PWM max range and resting value adjustment
2020-11-26 Radio buttons for arm/disarm drive/weapon
2020-11-26 Added individual control for motors on GUI
2020-11-27 started changing up radio buttons
2020-11-27 new radio buttons work
2020-11-28 Serial prints adjusted, write motor pwm
2020-11-28 Lowered pwm and fixed debounce issue
2020-12-13 Graph on Main window!!! Kinda slows down UI tho, need to fix that
    [mainWindow.py]
2020-12-14 new thread for each graph that updates it. graph bring up is a little slow but it's good after
2020-12-15 added labels for all sensor data
2020-12-16 cleaned up GUI code to organize by widget, fixed RC GUI flaw
    [mainWindow.py]
2020-12-20 fixed a print
2020-12-21 end match and reset
    [mainWindow.py]
2021-02-07 wifi comms fixed ESP32, firmware arm and disarm.
    [drive.py, main.cpp, mainWindow.py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]
2021-02-08 Working firmware and python version, arm disarm, current measurement
2021-02-08 modified IP stuff to connect to esp32
2021-02-17 added pid tuning from GUI
2021-02-18 implemented pid in firmware
2021-02-18 Motor pinouts updated, wifi connect mode
2021-02-19 set up pid mapping, may need tuning
2021-02-23 implemented pid bool, needs firmware-side testing
2021-02-25 trying to reset to prev commit
    [main.cpp]
2021-02-25 pid tuning fully functioning from gui with bool flag
2021-03-02 dynamically update heading on GUI works, still need to fix labels and cosmetic stuff
    [main.cpp, mainWindow.py]
2021-03-04 fixed pid tuning state so it doesn't switch to stopped state after
2021-03-04 fixed gui sensor labels, they display properly now but still need to fetch data other than heading
    [mainWindow.py]
2021-03-04 removed signal strength and orientation from gui sensor displays; added weapon and motor currents
2021-03-10 integrated CV into controls; CV thread cannot run its own GUI for thread safety reasons
2021-03-10 encoder code integrated into kristen branch, isr implementation reparied
2021-03-11 GYRO PI changes to limits
2021-03-11 mod 360 added to gyro turn
2021-03-11 stable gyro turning code tested
2021-03-11 Gyro heading set error check, json can now set the desired heading
    [main.cpp, movement.cpp]
2021-03-11 fixed a set heading bug
    [mainWindow.py]
2021-03-15 comment tweaks to gyro movement
2021-03-16 Removed old motor disable code, added ESTOP functionality
2021-03-18 Missing tracking tag error handling
    [drive.py, mainWindow.py]
2021-03-29 setHeading and setDistance buttons on GUI make robot move
2021-04-12 removed wifi print for fast
2021-04-15 Added pid target
2021-04-17 Fixed Camera Issues
2021-04-20 works! pix/inch updatede removed prints print errs drive to opponent IMU
2021-05-05 Electrical Updates
    [esp32Layout1.brd, esp32Layout1.sch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]

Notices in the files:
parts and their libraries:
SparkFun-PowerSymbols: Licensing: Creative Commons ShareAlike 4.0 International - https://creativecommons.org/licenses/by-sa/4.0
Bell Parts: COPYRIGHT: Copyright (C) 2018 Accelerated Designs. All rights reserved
